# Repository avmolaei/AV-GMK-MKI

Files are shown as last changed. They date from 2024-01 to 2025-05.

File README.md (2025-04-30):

# AV-GMK MK I

The AV-GMK MK I is the first iteration of the AVlabs AV-GMK, the AVlabs "normal Gaming Mechanical Keyboard.

It differs from previous AVlabs projects by the fact that it has a normal ISO AZERTY layout. However, the alpha keys are in a ortholinear layout.

Epic RGB lighting powered by SK6812-mini LEDs

Compatible with MX style switches.

## TODO: shit to do still:

FW: Most keyboard logic has been implemented, ported from AV-RK MK2. Notorious "cannot hold down key" bug of AV-RK MK2 has been fixed. LED modese have been implemented as follows: 

One mode should be off, duh. (5)

One mode should be green lighting (3)

One mode should be a lighting per zone (e.g one color for Fn keys, one color for alphanumeric, etc.). This is the default lighting mode upon power up (1 )
- NB: I am a bit lazy to implement a logic to modify on the fly the colors for each zone, so this will be hardcoded. A good improvement would be to do that on the fly and store the color scheme. 

One mode should be the rainbow wave.  (2)

One function should allow brightnes control (+ -)

One mode should be white. (4)

PCB: The "-" Key on the numpad is rotated 90° for some reason.

All stabilizer footprints are messed up, the radius of the hole for the clip is too small and the length between both mounting posts are fucked. Plastic post can be chopped down, and the other one can be screwed and it works normally, for peace of mind a slight point of glue can be added.

The stabilizer holes on the backspace key are way too small.

more LEDs should be added. while 1 LED/key is standard on most keyboard, it feels "empty" near big keys like the spacebar.

Add kailh choc footprints next to the MX holes for optimal switch compatibility

Implement the knob functionnality for volume controls. 

CAD: finish cad, duh.

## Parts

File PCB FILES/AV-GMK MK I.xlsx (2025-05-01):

where to get the shit | cost
1st keycap set | 15.99 €
2nd keycap set | 33.00 €
M3 Inserts | 12.40 €
durock pcb stab | 29.99 €
durock pcb stab | 29.99 €
akko cs matcha green (x135) | 65.97 €
SK6812MINI E RGB LEDs (x130) | 44.90 €
PCBs | 235.02 €
XIAO SAMD21 | 16.16 €
Lube and shit | 23.58 €
fancy ass cable | 10.91 €
filament | 22.79 €
total cost | 540.70 €

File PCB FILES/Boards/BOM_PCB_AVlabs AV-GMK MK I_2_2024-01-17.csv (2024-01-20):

ID | Name | Designator | Footprint | Quantity | Manufacturer Part | Manufacturer | Supplier | Supplier Part | Price
1 | 100nF | C5,C6,C3,C4,C1,C2 | C0805 | 6 | GRM21BR71H104KA01L | muRata(村田) | LCSC | C77082 | 0.008
2 | 1.1kΩ | R11,R12,R9,R10,R3,R4 | R0805 | 6 | RN732ATTD1101B25 | KOA | LCSC | C186476 | 0.078
3 | 2kΩ | R13,R8,R5 | R0805 | 3 | RN732ATTD2001B25 | KOA | LCSC | C186482 | 0.243
4 | 4.7kΩ | R14,R15,R6,R7,R1,R2 | R0805 | 6 | RN732ATTD4701B25 | KOA | LCSC | C186491 | 0.177
5 | beautiful-solderbridge | U17,U18,U19,U20,U21,U22,U11,U12,U13,U14,U15,U16,U4,U5,U6,U7,U8,U9 | BEAUTIFUL-SOLDER-BRIDGE | 18
6 | BSS138NH6327 | Q1 | SOT-23-3_L2.9-W1.3-P1.90-LS2.4-BR | 1 | BSS138NH6327 | Infineon(英飞凌) | LCSC | C94638 | 0.155
7 | 10kΩ | R16,R17 | R0805 | 2 | RN732ATTD1002B10 | KOA | LCSC | C782227 | 0.284
8 | PCA9505DGG,118 | U1,U10,U23 | TSSOP-56_L14.0-W6.1-P0.50-LS8.1-BL | 3 | PCA9505DGG,118 | NXP(恩智浦) | LCSC | C2669685 | 5.479
9 | CHERRYMX_1U_SK6812_MINI_E | SW0,SW1,SW2,SW3,SW4,SW5,SW6,SW7,SW8,SW9,SW10,SW11,SW12,SW13,SW14,SW15,SW16,SW17,SW18,SW19,SW20,SW21,SW22,SW23,SW24,SW25,SW26,SW28,SW29,SW31,SW32,SW33,SW34,SW35,SW36,SW37,SW38,SW40,SW41,SW42,SW43,SW44,SW45,SW46,SW47,SW48,SW49,SW50,SW52,SW53,SW55,SW56,SW57,SW58,SW59,SW60,SW61,SW62,SW64,SW65,SW66,SW67,SW68,SW69,SW70,SW71,SW72,SW73,SW74,SW75,SW76,SW78,SW80,SW81,SW82,SW83,SW84,SW85,SW86,SW87,SW88,SW89,SW91,SW92,SW93,SW94,SW95,SW96,SW97,SW98,SW99,SW100,SW101,SW102,SW104 | CHERRYMX_1U_SK6812_MINI-E | 95
10 | X6511WV-07H-C30D60 | H1,H3 | HDR-TH_7P-P2.54-V-M | 2 | X6511WV-07H-C30D60 | XKB Connectivity(中国星坤) | LCSC | C706879 | 0.107
11 | PCA_PINS | H9 | HDR-TH_3P-P2.54-V-M | 1 | X6511WV-03H-C30D60 | XKB Connectivity(中国星坤) | LCSC | C706875 | 0.052

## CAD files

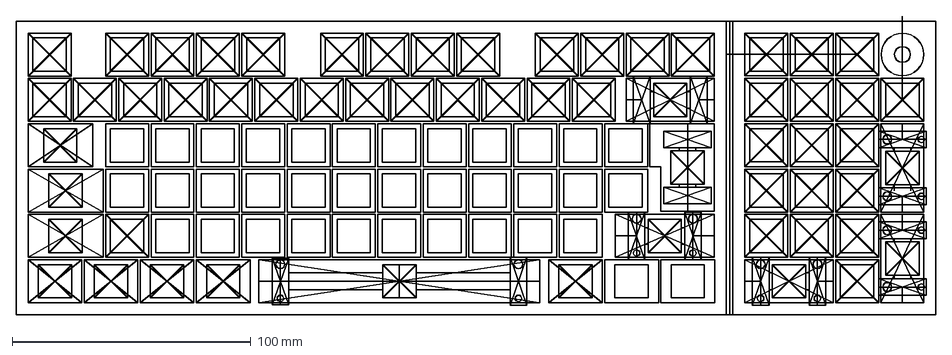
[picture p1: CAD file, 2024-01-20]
CAD FILES/keys/keyboard sketc.dxf
385.3 x 125.0 mm

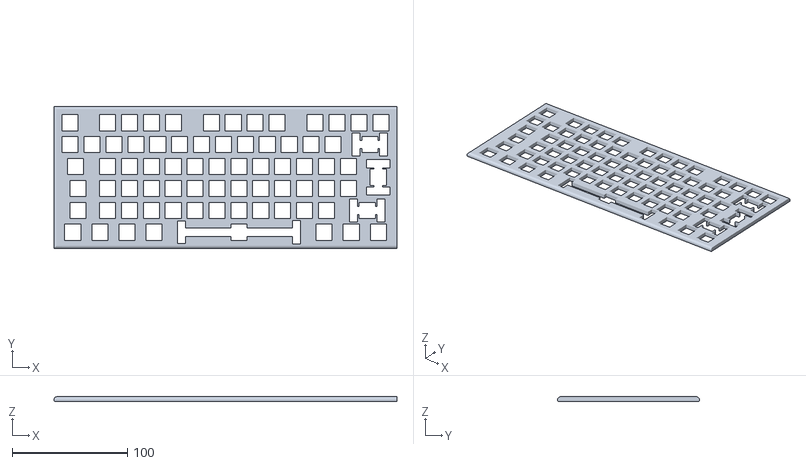
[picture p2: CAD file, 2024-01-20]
CAD FILES/test prints/Corps1.stl
297.5 x 123.0 x 4.00

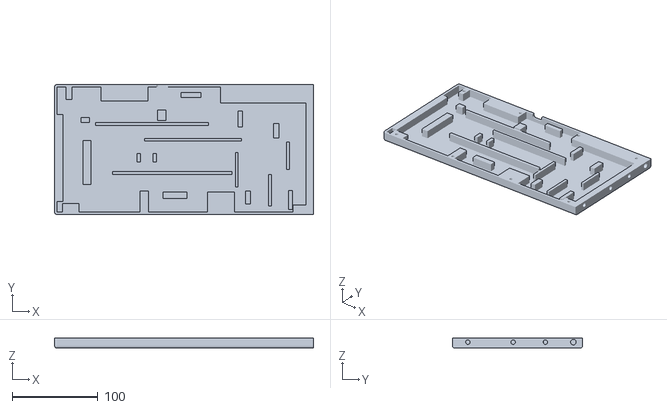
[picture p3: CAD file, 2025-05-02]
CAD FILES/V1/bot alpha.stl
301.8 x 151.7 x 12.0

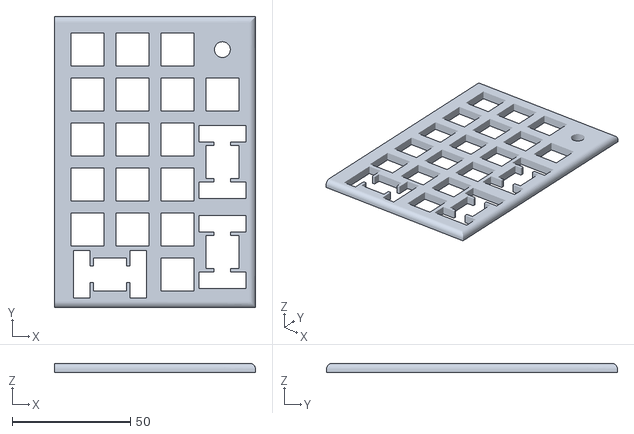
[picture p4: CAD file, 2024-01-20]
CAD FILES/test prints/Corps2.stl
85.0 x 123.0 x 4.00

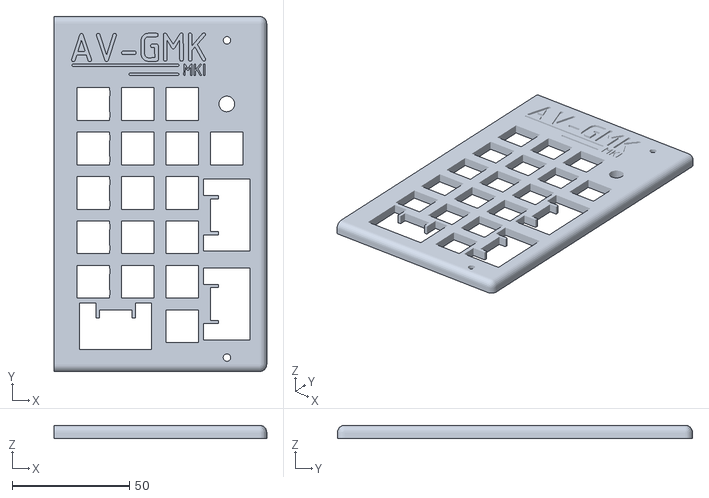
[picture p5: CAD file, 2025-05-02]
CAD FILES/V1/top num 2.stl
90.8 x 151.7 x 5.72

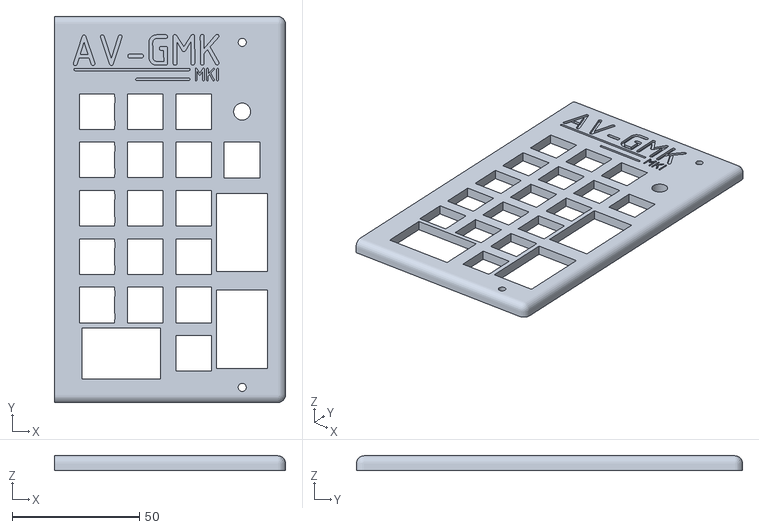
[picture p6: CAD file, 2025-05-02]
CAD FILES/V1/top num.stl
90.8 x 151.7 x 5.72

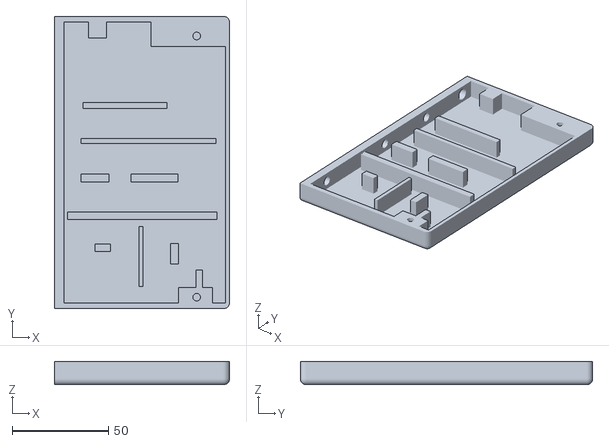
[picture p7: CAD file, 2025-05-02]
CAD FILES/V1/bot num.stl
90.8 x 151.7 x 12.0

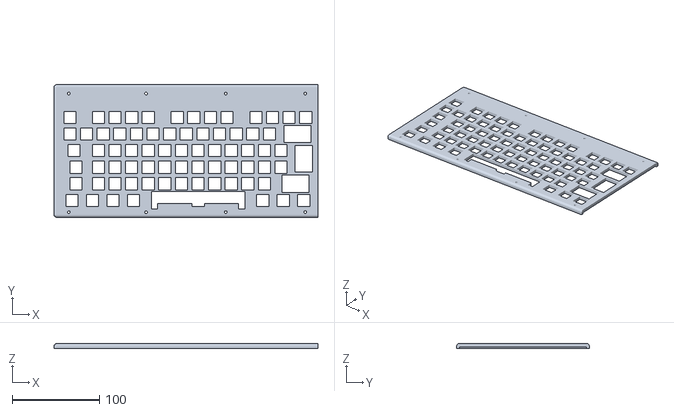
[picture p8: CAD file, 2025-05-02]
CAD FILES/V1/top alpha.stl
301.8 x 151.7 x 5.72

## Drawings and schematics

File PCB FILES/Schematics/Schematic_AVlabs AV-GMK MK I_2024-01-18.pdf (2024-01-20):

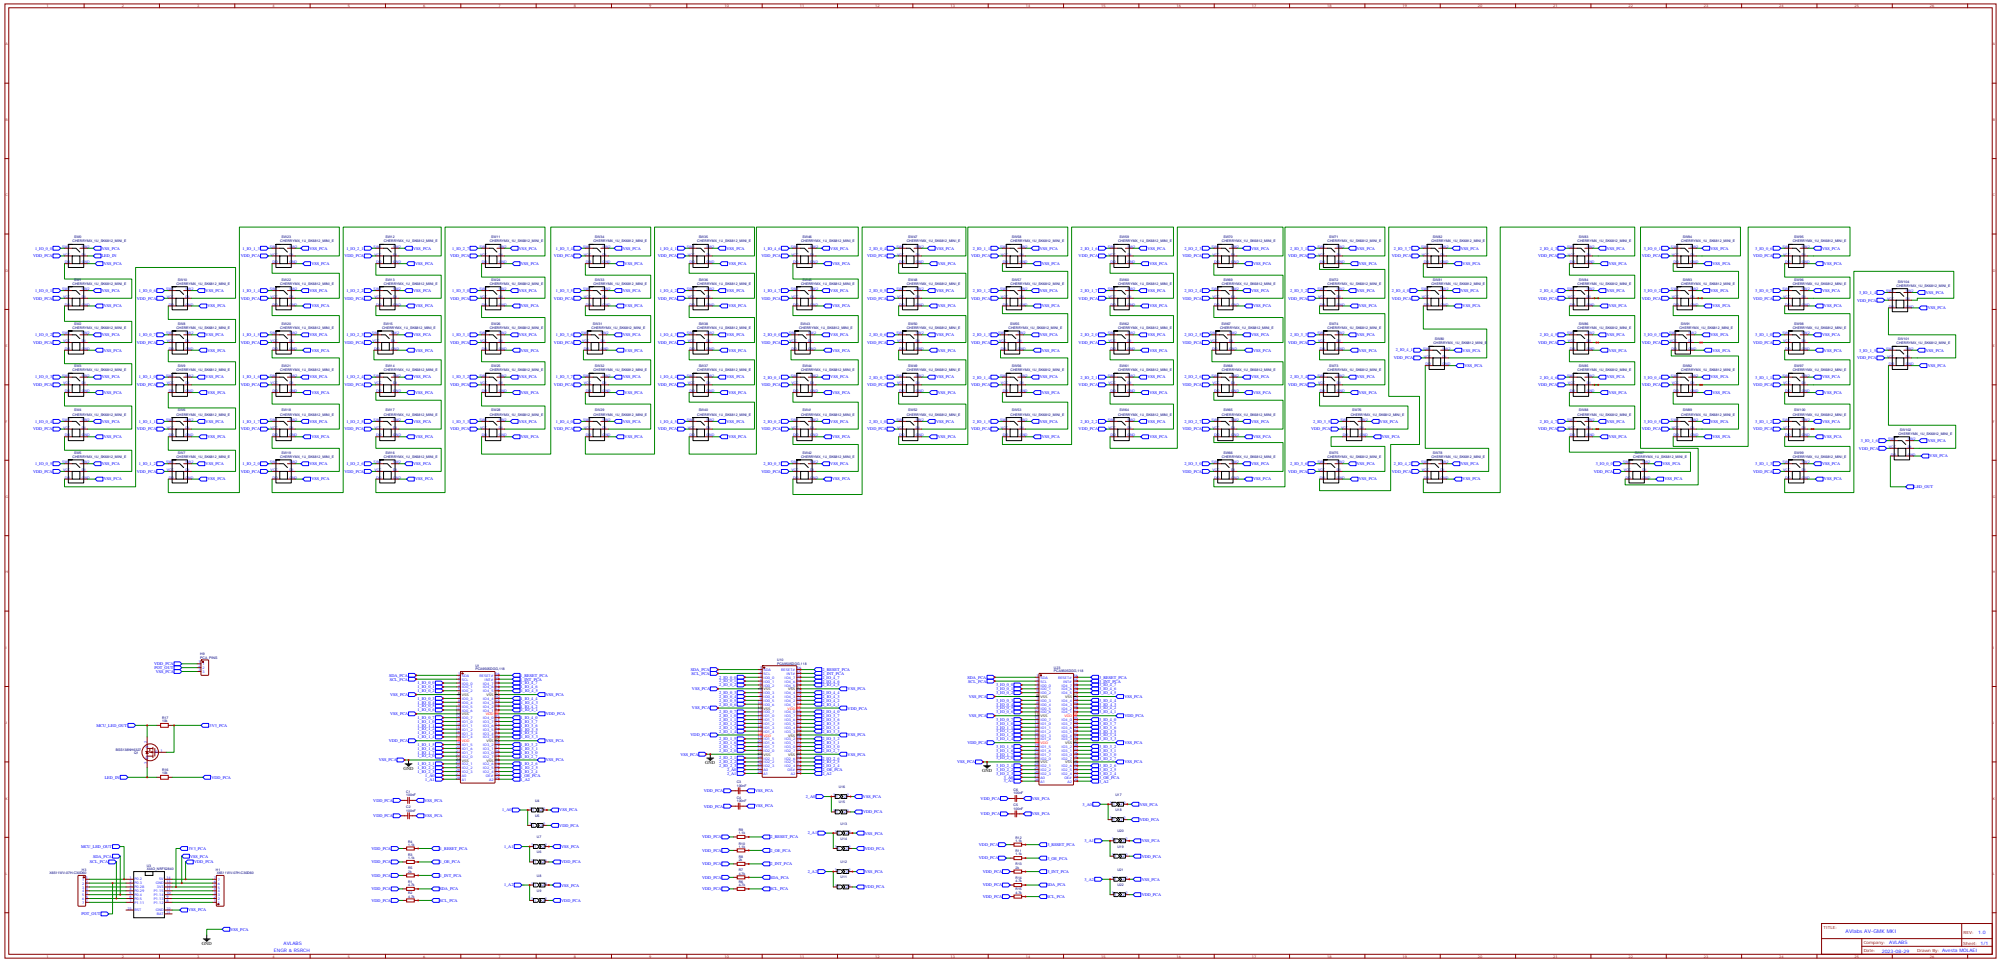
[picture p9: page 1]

Drawn By: Avesta MOLAEI

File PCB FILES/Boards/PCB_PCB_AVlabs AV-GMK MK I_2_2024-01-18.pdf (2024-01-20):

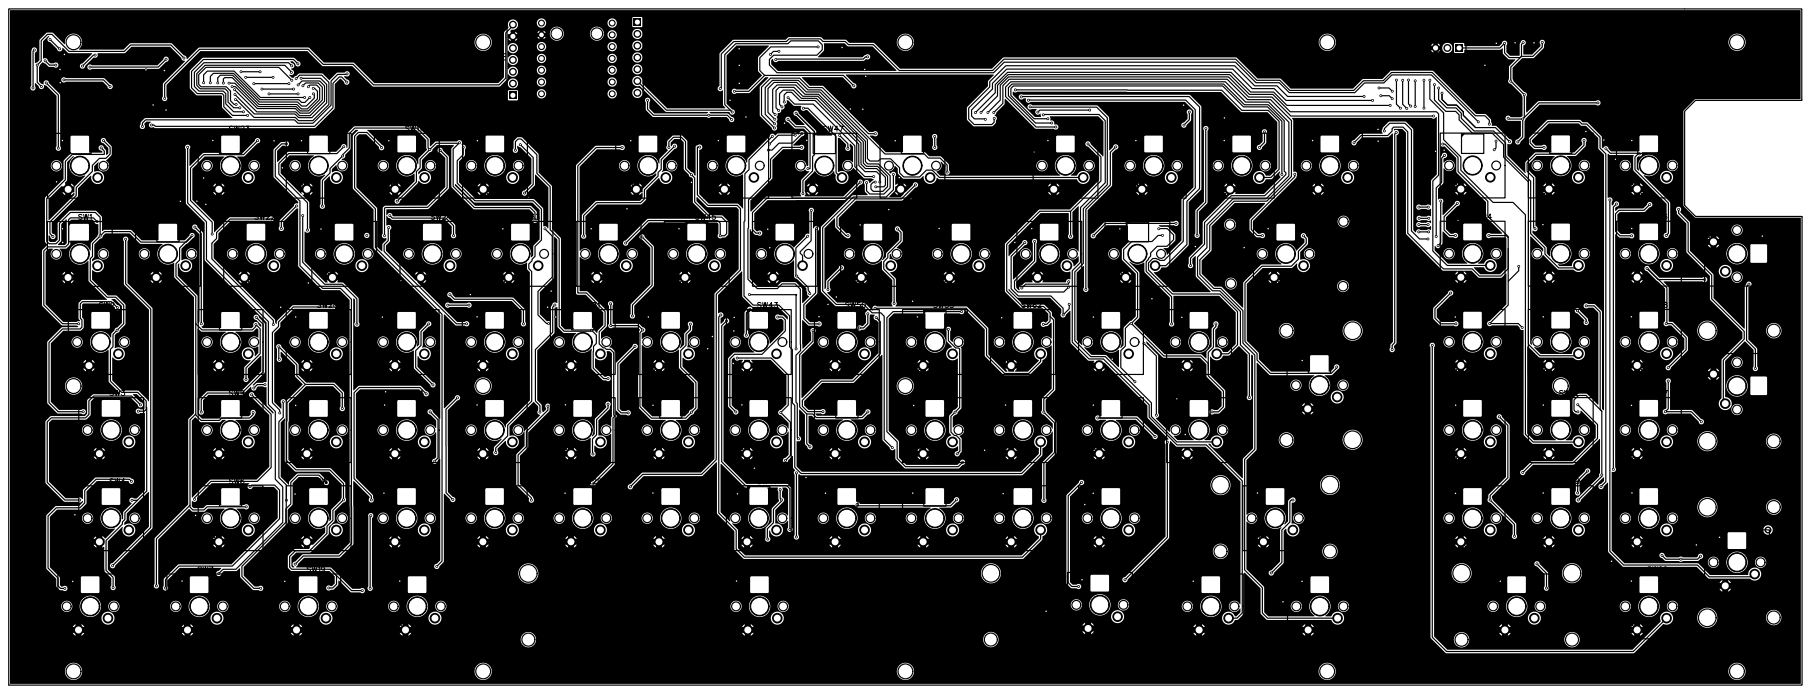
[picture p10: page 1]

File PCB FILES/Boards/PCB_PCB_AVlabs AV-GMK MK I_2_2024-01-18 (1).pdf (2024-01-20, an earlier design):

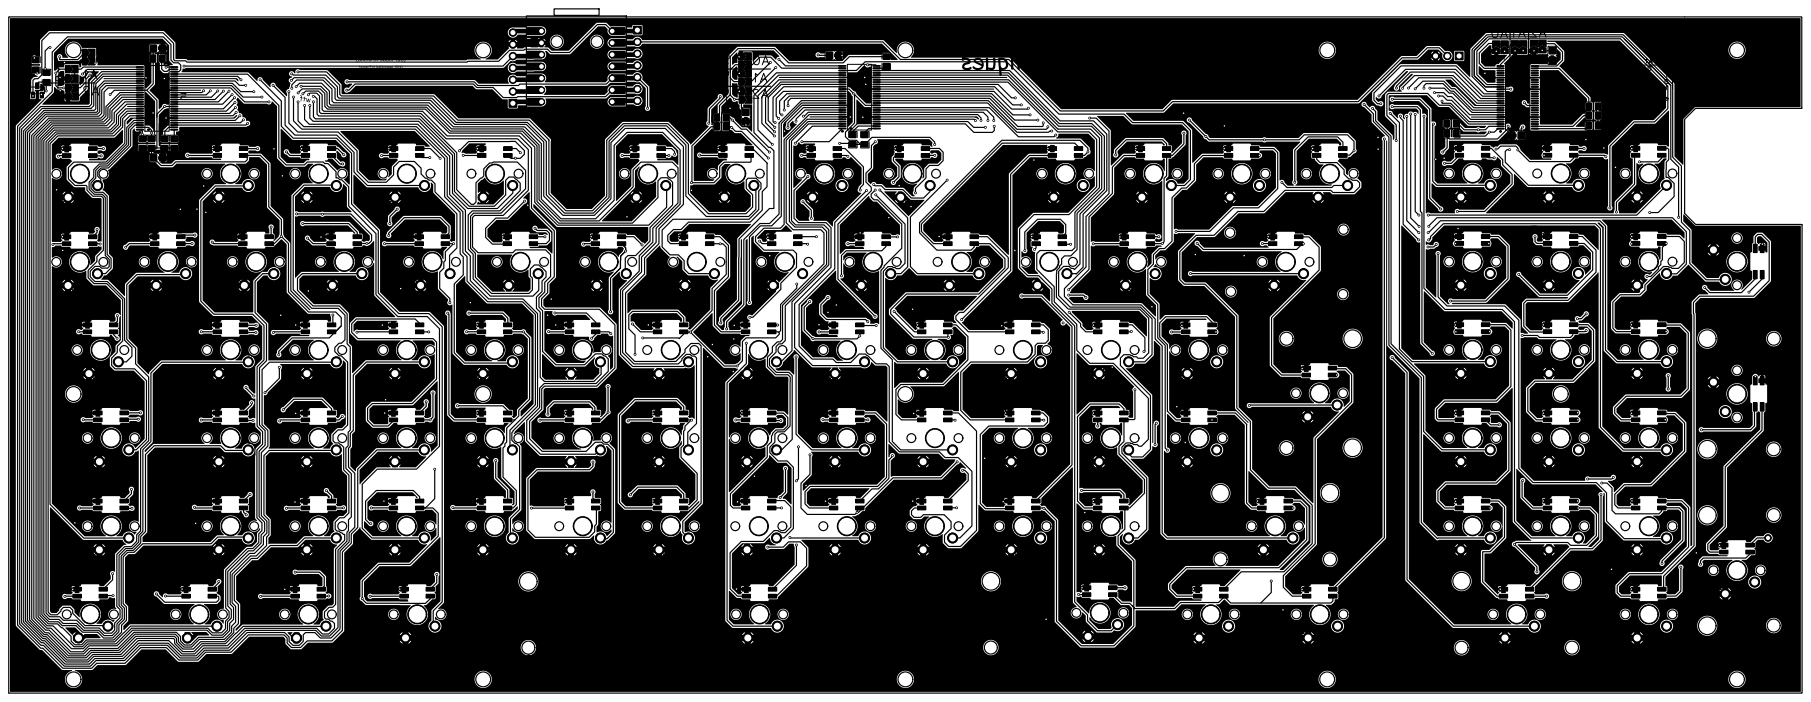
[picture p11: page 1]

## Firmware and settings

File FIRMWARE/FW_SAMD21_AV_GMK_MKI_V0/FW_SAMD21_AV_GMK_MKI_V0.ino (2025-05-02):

#include <PCA9505_9506.h>
#include <Keyboard.h> 
#include <Adafruit_NeoPixel.h> 
//delays for the key actuation
#define INITIAL_DELAY 250
#define REPEAT_DELAY 5

//values for the min and max LED brightnesses, and the step
#define MIN_BRIGHTNESS 2  
#define MAX_BRIGHTNESS 255
#define BRIGHTNESS_STEP 2

// Color definitions
#define COLOR_MODIF strip.Color(255, 0, 0) 
#define COLOR_NUMBER strip.Color(0, 255, 0)
#define COLOR_LETTER strip.Color(0, 0, 255) 
#define COLOR_NUMPAD strip.Color(255, 255, 255) 
#define COLOR_SPECIAL strip.Color(255, 255, 0) 



//custom keys
#define KEY_FUNCTION 0xFB
#define KEY_CHEVRON_L 236
#define KEY_CHEVRON_R 236
#define KEY_SCREENSHOT 0xFA 

//customs keys for module control
#define KEY_MOD_1 0xF9  
#define KEY_MOD_2 0xF8  
#define KEY_MOD_3 0xF7  
#define KEY_MOD_4 0xF6  
#define KEY_MOD_5 0xF5  
#define KEY_MOD_P 0xFC  
#define KEY_MOD_M 0xFD



// Define the IO expander objects and the number of keys per expander
PCA9505_06 NUMPAD;
PCA9505_06 LEFT;
PCA9505_06 RIGHT;
const uint8_t numKeys = 40;


char keyMapLEFT[numKeys] = {
  KEY_ESC, '`', KEY_TAB, KEY_CAPS_LOCK, KEY_LEFT_SHIFT, KEY_LEFT_CTRL,
          '1', 'q', 'a', KEY_CHEVRON_L, KEY_LEFT_GUI,
  KEY_F1, '2', 'w', 's', 'z', KEY_LEFT_ALT,
  KEY_F2, '3', 'e', 'd', 'x', KEY_FUNCTION,
  KEY_F3, '4', 'r', 'f', 'c',
  KEY_F4, '5', 't', 'g', 'v',
  KEY_F5, '6', 'y', 'h', 'b',
  KEY_F6, '7'
};
char keyMapLEFTALT[numKeys] = {
  KEY_ESC, '`', KEY_TAB, KEY_CAPS_LOCK, KEY_LEFT_SHIFT, KEY_LEFT_CTRL,
  '1', 'q', 'a', KEY_CHEVRON_L, KEY_LEFT_GUI,
  KEY_F1, '2', 'w', 's', 'z', KEY_LEFT_ALT,
  KEY_F2, '3', 'e', 'd', 'x', KEY_FUNCTION,
  KEY_F3, '4', 'r', 'f', 'c',
  KEY_F4, '5', 't', 'g', 'v',
  KEY_F5, '6', 'y', 'h', 'b',
  KEY_F6, '7'
};
char keyMapRIGHT[numKeys] = {
              'u', 'j', 'n', ' ',
  KEY_F7, '8', 'i', 'k', 'm',
  KEY_F8, '9', 'o', 'l', ',',
  KEY_F9, '0', 'p', ';', '.',
  KEY_F10, '-', '[', '\'', '/', KEY_RIGHT_ALT,
  KEY_F11, '=', ']', '\\', KEY_RIGHT_SHIFT, KEY_MENU,
  KEY_F12, KEY_BACKSPACE, KEY_RETURN, KEY_RIGHT_CTRL,
  KEY_PRINT_SCREEN, KEY_NUM_LOCK, KEY_KP_7, KEY_KP_4, KEY_KP_1
};
char keyMapRIGHTALT[numKeys] = {
  'u', 'j', 'n', ' ',
  KEY_F7, '8', 'i', 'k', 'm',
  KEY_F8, '9', 'o', 'l', ',',
  KEY_F9, '0', 'p', ';', '.',
  KEY_F10, '-', '[', '\'', '/', KEY_RIGHT_ALT,
  KEY_F11, '=', ']', '\\', KEY_RIGHT_SHIFT, KEY_MENU,
  KEY_F12, KEY_BACKSPACE, KEY_RETURN, KEY_RIGHT_CTRL,
  KEY_SCREENSHOT, KEY_NUM_LOCK, KEY_KP_7, KEY_MOD_4, KEY_MOD_1

};
char keyMapNUMPAD[numKeys] = {
  KEY_KP_0,
  KEY_PAGE_UP, KEY_KP_SLASH, KEY_KP_8, KEY_KP_5, KEY_KP_2,
  KEY_PAGE_DOWN, KEY_KP_ASTERISK, KEY_KP_9, KEY_KP_6, KEY_KP_3, KEY_KP_DOT,
  KEY_KP_MINUS, KEY_KP_PLUS, KEY_KP_ENTER
};
char keyMapNUMPADALT[numKeys] = {
  KEY_KP_0,
  KEY_PAGE_UP, KEY_KP_SLASH, KEY_KP_8, KEY_MOD_5, KEY_MOD_2,
  KEY_HOME, KEY_KP_ASTERISK, KEY_KP_9, KEY_KP_6, KEY_MOD_3, KEY_KP_DOT,
  KEY_MOD_M, KEY_MOD_P, KEY_KP_ENTER
};


bool keyStateNP[numKeys] = { 0 };
bool keyStateL[numKeys] = { 0 };
bool keyStateR[numKeys] = { 0 };

bool isShiftPressed = false;
bool isCapsLockOn = false;
bool initialDelayPassed = false;

unsigned long lastPressTime;
unsigned long lastToggleTime = 0;
uint8_t lastKeyPressed = 255;


uint32_t lastUpdate = 0;  // Last update of position
uint16_t j = 0;           // Position in the rainbow



//LED variables
const uint8_t ledPin = 0;         
const uint8_t numLeds = 95;     
Adafruit_NeoPixel strip = Adafruit_NeoPixel(numLeds, ledPin, NEO_GRB + NEO_KHZ800);
uint8_t currentBrightness = 50; 
uint8_t currentKeyMod = 0;
uint8_t startLedIndexLeft = 0; 
uint8_t startLedIndexRight = 40;
uint8_t startLedIndexNumpad = 80;

const int potPin = A1; 
int lastVolume = 0; 
unsigned long lastTime = 0; 
const long interval = 100; 






// Prototypes
void checkKeys(PCA9505_06& expander, char* keyMap, char* funcKeyMap, bool* keyState, bool funcKeyPressed);
void rainbow(uint8_t wait);
uint32_t wheel(byte wheelPos);
bool isModifier(char key);
bool isNumber(char key);
bool isLetter(char key);
bool isNumpadCharacter(char key);
bool isSpecialCharacter(char key);
void applyKeymapLighting(char keyMap[], uint8_t numKeys, uint8_t startLedIndex);



void setup() {

  Serial.begin(9600); 
  // Initialize the LEDs
  strip.begin();
  strip.setBrightness(currentBrightness);


  // Initialize the IO expanders
  NUMPAD.begin(0x23);  // Adjust the address as needed
  LEFT.begin(0x22);    // Adjust the address as needed
  RIGHT.begin(0x21);   // Adjust the address as needed

  // Set all pins as inputs
  for (uint8_t i = 0; i < numKeys; i++) {
    NUMPAD.pinMode(i, INPUT);
    LEFT.pinMode(i, INPUT);
    RIGHT.pinMode(i, INPUT);
  } 
   pinMode(potPin, INPUT);
}

void loop() {
  // Assign the Function Key
  bool funcKeyPressed = ((LEFT.digitalRead(22) == 0));

  // Check all the expanders with their keymaps and keystates
  checkKeys(NUMPAD, keyMapNUMPAD, keyMapNUMPADALT, keyStateNP, funcKeyPressed);
  checkKeys(LEFT, keyMapLEFT, keyMapLEFTALT, keyStateL, funcKeyPressed);
  checkKeys(RIGHT, keyMapRIGHT, keyMapRIGHTALT, keyStateR, funcKeyPressed);


  // Do the rainbow wave if called
  
  if (currentKeyMod == 2) {
    rainbow(1); // Keep the rainbow effect running
  }
  else if(currentKeyMod == 1){
    applyKeymapLighting(keyMapLEFT, numKeys, startLedIndexLeft); 
    applyKeymapLighting(keyMapRIGHT, numKeys, startLedIndexRight); 
    applyKeymapLighting(keyMapNUMPAD, numKeys, startLedIndexNumpad); 


  } /*
unsigned long currentTime = millis();
if (currentTime - lastTime >= interval) {
  int potValue = analogRead(potPin);
  int volumeLevel = map(potValue, 0, 1023, 0, 10000); // plage 0–100 pour plus de stabilité

  if (abs(volumeLevel - lastVolume) > 2) { // pour éviter les petits changements
    if (volumeLevel > lastVolume) {
      Keyboard.press(KEY_F15);  // Volume up
      Keyboard.release(KEY_F15);
      Serial.print("up");
    } else {
      Keyboard.press(KEY_F16);  // Volume down
      Keyboard.release(KEY_F16);
      Serial.print("down");
    }

    lastVolume = volumeLevel;
    lastTime = currentTime;
  }
}*/

}

/**
 * @brief Checks the state of each key connected to a specific PCA9505 chip, triggers key press/release actions, and handles mouse clicks.
 *
 * This function iterates over each key connected to the PCA9505 chip, represented by a PCA9505_06 object, and checks whether the state of the key has changed
 * (i.e., it has been pressed or released). It triggers the appropriate key press/release actions based on the current state of the keys and supports handling
 * mouse clicks. If a "function" key is pressed, the function switches to an alternative keymap layer defined by the function keymap.
 *
 * @param expander Reference to the PCA9505_06 object representing the PCA9505 chip to be checked.
 * @param keyMap Pointer to the array containing the primary keymap for the PCA9505 chip.
 * @param keyMapFunction Pointer to the array containing the function keymap for the PCA9505 chip.
 * @param keyState Pointer to the array containing the current state of each key connected to the PCA9505 chip.
 *
 * @note The function keymap is activated when the "function" key, represented by KEY_FUNCTION, is pressed.
 * @note MOUSE_LEFT_CLICK and MOUSE_RIGHT_CLICK are special constants used to represent mouse click actions.
 */
void checkKeys(PCA9505_06& expander, char* keyMap, char* funcKeyMap, bool* keyState, bool funcKeyPressed) {
  for (uint8_t i = 0; i < numKeys; i++) {
    unsigned long currentPressTime = millis();
    bool isPressed = (expander.digitalRead(i) == 0);
    char key = funcKeyPressed ? funcKeyMap[i] : keyMap[i];
    if (isPressed != keyState[i]) {
      keyState[i] = isPressed;
      switch (key) {
        case KEY_SCREENSHOT:
          if (isPressed) {
            Keyboard.press(KEY_LEFT_GUI);
            Keyboard.press(KEY_LEFT_SHIFT);
            Keyboard.press('s');
            delay(50);
            Keyboard.releaseAll();
            lastPressTime = millis();
            lastKeyPressed = i;
            initialDelayPassed = false;
          }
          break;
        case KEY_CHEVRON_L:
          if (isPressed) {
            if (isCapsLockOn || isShiftPressed) {
              Keyboard.press(KEY_LEFT_SHIFT);
              Keyboard.press(KEY_CHEVRON_L);
              Keyboard.releaseAll();
            } else {
              Keyboard.press(KEY_CHEVRON_R);
              Keyboard.release(KEY_CHEVRON_R);
            }
            lastPressTime = millis();
            lastKeyPressed = i;
            initialDelayPassed = false;
          }
          break;
        case KEY_MOD_1:
          currentKeyMod = 1;
          break;
        case KEY_MOD_2:
          currentKeyMod = 2;
          break;
        case KEY_MOD_3:
          for(int i = 0; i < strip.numPixels(); i++) {
            strip.setPixelColor(i, strip.Color(0, 255, 0)); // Set all pixels to 
          }
          
          strip.setBrightness(currentBrightness);
          strip.show();
          currentKeyMod = 3;
          break;
        case KEY_MOD_4:
          for(int i = 0; i < strip.numPixels(); i++) {
            strip.setPixelColor(i, strip.Color(255, 255, 255)); // Set all pixels to white
          }
          
          strip.setBrightness(currentBrightness);
          strip.show();
          break; 
          currentKeyMod = 4;
        case KEY_MOD_5:
          for(int i = 0; i < strip.numPixels(); i++) {
            strip.setPixelColor(i, strip.Color(0, 0, 0)); // Turn off all pixels
          }
          
          strip.setBrightness(currentBrightness);
          strip.show();
          currentKeyMod = 5;
          break;
        case KEY_MOD_P: // Increase brightness
            currentBrightness += BRIGHTNESS_STEP; // Adjust the step size as needed
            if (currentBrightness > MAX_BRIGHTNESS) 
              currentBrightness = MAX_BRIGHTNESS; // Ensure the brightness doesn't exceed MAX_BRIGHTNESS
            strip.setBrightness(currentBrightness);
            strip.show(); // Apply the new brightness
            break;

        case KEY_MOD_M: // Decrease brightness
            currentBrightness -= BRIGHTNESS_STEP; // Adjust the step size as needed
            if (currentBrightness < MIN_BRIGHTNESS) 
              currentBrightness = MIN_BRIGHTNESS; // Ensure the brightness doesn't drop below MIN_BRIGHTNESS
            strip.setBrightness(currentBrightness);
            strip.show(); // Apply the new brightness
            break;

        default:
          if (isPressed) {
            Keyboard.press(key);
            lastPressTime = millis();
            lastKeyPressed = i;
            initialDelayPassed = false;
          } else {  
            Keyboard.release(key);
            if (i == lastKeyPressed) lastKeyPressed = 255;
          }
          break;
      }
    }
  }
/* //2025 EDIT: DO NOT IMPLEMENT THIS FUNCTION!!!! AS A GOOD ELECTRICAL ENGINEERING I WANTED TO IMPLEMENT DEBOUNCING, BUT IT'S ALREADY BUILT IN KEYBOARD.h!!!!!
   //Commenting it out works. 
  //If you press a key once, it waits for INITIAL_DELAY, then if the key is still pressed, it spams it with a delay of REPEAT_DELAY in between each key press.
  if (lastKeyPressed != 255 && keyState[lastKeyPressed] && ((millis() - lastPressTime > INITIAL_DELAY && !initialDelayPassed) || (initialDelayPassed && millis() - lastPressTime > REPEAT_DELAY))) {
    char key = funcKeyPressed ? funcKeyMap[lastKeyPressed] : keyMap[lastKeyPressed];
      Keyboard.release(key);
      Keyboard.press(key);
      lastPressTime = millis();
      initialDelayPassed = true;
    }*/

}

void rainbow(uint8_t wait) {
  uint32_t currentMillis = millis();
  if (currentMillis - lastUpdate > wait) {
    lastUpdate = currentMillis;  // Save the last update time

    // Only update the LED strip if the specified 'wait' time has passed
    for (uint16_t i = 0; i < strip.numPixels(); i++) {
      strip.setPixelColor(i, wheel((i * 1 + j) & 255));
    }
    strip.show();

    // Increment 'j', reset if it reaches 256
    j+= 5;
    if (j >= 256) {
      j = 0;
    }
  }
}

uint32_t wheel(byte wheelPos) {
  if (wheelPos < 85) {
    return strip.Color(wheelPos * 3, 255 - wheelPos * 3, 0);
  } else if (wheelPos < 170) {
    wheelPos -= 85;
    return strip.Color(255 - wheelPos * 3, 0, wheelPos * 3);
  } else {
    wheelPos -= 170;
    return strip.Color(0, wheelPos * 3, 255 - wheelPos * 3);
  }
}

void applyKeymapLighting(char keyMap[], uint8_t numKeys, uint8_t startLedIndex) {
    for (uint8_t i = 0; i < numKeys; i++) {
        char key = keyMap[i];
        uint32_t color = 0;
        
        if (isModifier(key)) {
            color = COLOR_MODIF;
        } else if (isNumber(key)) {
            color = COLOR_NUMBER;
        } else if (isLetter(key)) {
            color = COLOR_LETTER;
        } else if (isNumpadCharacter(key)) {
            color = COLOR_NUMPAD;
        } else if (isSpecialCharacter(key)) {
            color = COLOR_SPECIAL;
        }

        strip.setPixelColor(i + startLedIndex, color);
    }
    strip.show();
}


bool isModifier(char key) {
    return key == KEY_LEFT_CTRL || key == KEY_LEFT_SHIFT || key == KEY_LEFT_ALT || 
           key == KEY_RIGHT_CTRL || key == KEY_RIGHT_SHIFT || key == KEY_RIGHT_ALT ||
           key == KEY_FUNCTION || key == KEY_LEFT_GUI || key == KEY_RIGHT_GUI || key == KEY_TAB  
           || key == KEY_CAPS_LOCK || key == KEY_MENU  || key == KEY_RETURN || key == KEY_BACKSPACE ||

           key == KEY_F1 || key == KEY_F2 || key == KEY_F3 || key == KEY_F4 || 
           key == KEY_F5 || key == KEY_F6 || key == KEY_F7 || key == KEY_F8 || 
           key == KEY_F9 || key == KEY_F10 || key == KEY_F11 || key == KEY_F12 ||
           
           key == KEY_PAGE_UP || key == KEY_PAGE_DOWN || key == KEY_PRINT_SCREEN || key == KEY_NUM_LOCK ||
           key == KEY_ESC;
}

bool isNumber(char key) {
    return key >= '0' && key <= '9' || key == '`' || key =='=' || key =='-';
}

bool isLetter(char key) {
    return (key >= 'a' && key <= 'z') || (key >= 'A' && key <= 'Z') || key == ' ';
}
bool isSpecialCharacter(char key) {
    return    key == 'm'|| key == ';' || key == ',' || key == '.' || key == '/'  || key == '\\' || key == '\''
    || key == '[' || key == ']' || key ==KEY_CHEVRON_L;
}

bool isNumpadCharacter(char key) {
    return key == KEY_KP_0 || key == KEY_KP_1 || key == KEY_KP_2 || 
           key == KEY_KP_3 || key == KEY_KP_4 || key == KEY_KP_5 || 
           key == KEY_KP_6 || key == KEY_KP_7 || key == KEY_KP_8 || 
           key == KEY_KP_9 || key == KEY_KP_PLUS || key == KEY_KP_MINUS || 
           key == KEY_KP_SLASH || key == KEY_KP_ASTERISK || key == KEY_KP_ENTER || 
           key == KEY_KP_DOT;
}

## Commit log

2024-01-20 added PCB files and first CAD tests
    [AV-GMK MK I.xlsx, BOM_PCB_AVlabs AV-GMK MK I_2_2024-01-17.csv, Corps1.stl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]
2024-01-28 added firmware, basic working version for left PCA + LEDs
2024-02-03 fixed most keyboard related stuff, implemented LED handling. All that remains is the per zone lighting mode
    [FW_SAMD21_AV_GMK_MKI_V0.ino]
2025-05-01 updated xlsx
    [AV-GMK MK I.xlsx]
2025-05-02 fucking stabilizers. Fixed cad a bit?
    [bot alpha.stl, bot num.stl, top alpha.stl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]
